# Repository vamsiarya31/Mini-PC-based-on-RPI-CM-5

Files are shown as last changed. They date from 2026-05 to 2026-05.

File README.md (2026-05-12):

# Mini PC — Raspberry Pi Compute Module 5 Carrier Board | KiCad PCB Design

A KiCad-designed **custom carrier board** for the **Raspberry Pi Compute Module 5 (CM5)**, forming a fully functional **Linux-capable Mini PC**. The board interfaces directly with the CM5 module and exposes USB-C, HDMI video output, and microSD Linux boot, powered by a dedicated battery charging and regulation architecture — all designed as a compact multi-sheet hierarchical KiCad project.

You will find the following:
- **Board Schematic:** Hierarchical multi-sheet schematic covering the CM5 interface, HDMI output, USB-C connectivity, microSD boot, battery management, and voltage regulation.
- **PCB Layout:** The physical design of the printed circuit board with component placement and keep-out zones.
- **PCB Routing:** Signal and power routing across the two-layer board following CM5 hardware design guidelines.

---

### Tools Used

The electronic design and development were done using **KiCad**, an open-source EDA software.
The version used for this project is **KiCad 9.0.7**.

#### Footprints used for LEDs:
`0603_1608Metric_Pad1.08x0.95mm_HandSolder`

#### Footprints used for Resistors, Capacitors, Inductors:
`0402_1005Metric_Pad1.22x1.35mm_HandSolder`

All the files are attached in the repository folder.

A custom library was created to import certain symbols into the schematic along with their corresponding footprints and 3D models.

The name of the library is:
- **My library.pretty** : for footprints

---

## System Architecture

The design is organised into **8 hierarchical KiCad sub-sheets**:

| Sub-sheet | File | Function |
|---|---|---|
| RPI-CM5 | `rpicm5.kicad_sch` | CM5108064 module — all peripheral signal routing |
| HDMI | `hdmi.kicad_sch` | HDMI Type-A connector + DDC pull-ups + HPD |
| USB-C | `usbc.kicad_sch` | USB-C receptacle (16-pin, USB 2.0) + CC resistors |
| SD-CARD | `sd.kicad_sch` | MicroSD card slot — 4-bit SDIO boot interface |
| Power Management | `pm.kicad_sch` | MCP73831 Li-Po charger + charging status LED |
| Buck | `buck.kicad_sch` | TPS63001 buck-boost — stable 3.3V from battery input |
| LDO | `ldo.kicad_sch` | LM1117LD-1.8 LDO — fixed 1.8V from regulated input |
| Battery Connector | `bat.kicad_sch` | 2-pin Li-Po battery input connector (J1) |

---

## CM5 Module Interface

The **Raspberry Pi CM5 (CM5108064)** is the central compute element, split across two symbol units (**U1A** and **U1B**) in the schematic to manage its large pin count:

| Interface | CM5 Pins | Carrier Function |
|---|---|---|
| +5V Supply (Input) | 77, 98, 135 | Carrier 5V power rail into CM5 |
| CM5_3.3V (Output) | 84, 86 | CM5-generated 3.3V — internal use |
| CM5_1.8V (Output) | 88, 90 | CM5-generated 1.8V — feeds `1.8v` net on carrier |
| HDMI0 Clock | HDMI0_CLK_P/N (188/190) | Differential clock to HDMI connector |
| HDMI0 TX0–TX2 | TX0_P/N, TX1_P/N, TX2_P/N | TMDS data lanes to HDMI connector |
| HDMI0 Control | HDMI0_SCL (200), HDMI0_SDA (199), HDMI0_HOTPLUG (153) | DDC I2C + HPD to HDMI connector |
| USB 2.0 | USB_P (105), USB_N (103) | D+/D− routed to USB-C receptacle |
| SD Interface | SD_CLK (57), SD_CMD (62), SD_DAT0–3 (63/67/69/61) | 4-bit SDIO to microSD slot |
| CC Pull-downs | CC1 (94), CC2 (96) | 5.1 kΩ to GND — configures USB-C device mode |

> **Note:** The CM5 contains its own onboard PMIC that generates all internal rails. The carrier only needs to supply a clean **+5V** to the module's power input pins. The CM5_1.8V output is re-used on the `1.8v` net for carrier-level peripherals.

---

## Key ICs & Design Decisions

### HDMI Output — HDMI Type-A (J4)
- Driven directly by CM5's **HDMI0** peripheral — no external HDMI bridge or level-shifter required
- **TMDS differential pairs** (TX0, TX1, TX2, CLK) routed from CM5 U1B directly to the J4 HDMI_A connector
- **DDC I2C** (SCL/SDA) lines pulled up to 5V via **R9 and R10 (4.7 kΩ each)** for EDID communication with the connected display
- **HPD (Hot-Plug Detect)** pulled up to 5V via **R15 (5.1 kΩ)** — signals monitor presence back to the CM5
- Local decoupling on the connector's 5V supply: **C5 (10 µF) + C6 (0.1 µF)** bulk + bypass

### USB-C — USB 2.0 (J2, USB_C_Receptacle_USB2.0_16P)
- 16-pin USB-C receptacle wired for **USB 2.0 only** — D+ and D− sourced from CM5 USB_P/USB_N pins
- **CC1 and CC2** each pulled down to GND via **R3 and R4 (5.1 kΩ)** — identifies the port as a **USB device (UFP)** and signals a standard 5V/900 mA draw to the host charger
- No active PD controller — the 5.1 kΩ CC resistors alone are sufficient for charger recognition and device-mode configuration
- **VBUS** from the USB-C receptacle is fed into the Power Management sheet as the charging source for the MCP73831

### MicroSD Boot Slot — J5 (Micro_SD_Card)
- Wired to CM5 SDIO in **4-bit mode**: CLK, CMD, DAT0, DAT1, DAT2, DAT3
- All data and command lines pulled up to **3.3V via 10 kΩ resistors** (R5, R6, R7, R8, R14) for clean defined idle states
- **DAT3/CD** pin doubles as card-detect — pulled up on-board for card presence signalling
- Slot powered by the **3p3v** rail with local decoupling: **C3 (10 µF) + C4 (0.1 µF)**
- Compatible with all standard Linux ARM64 boot images (Raspberry Pi OS, Ubuntu Server, etc.)

### Power Architecture

| Stage | IC / Component | Role |
|---|---|---|
| Battery Input | J1 (Conn_01x02) | 2-pin Li-Po battery connector — `BatP` net |
| Li-Po Charger | MCP73831T-2ACI_OT (U2) | Single-cell Li-Ion/Li-Po charger, input from USB-C VBUS |
| Charge Current | R11 (2 kΩ) on PROG pin | Sets charge current: `I = 1000 / 2kΩ` = **500 mA** |
| Charge Status LED | D1 (RED) + R12 (560 Ω) | STAT pin drives LED — ON during charging, OFF when complete |
| Charger Decoupling | C7 + C8 (4.7 µF each) | Stabilises MCP73831 VDD and VBAT rails |
| 3.3V Regulation | TPS63001 (U3) — Buck-Boost | Stable 3.3V (`3p3v`) across full Li-Po discharge range |
| 3.3V Inductor | L1 (2.2 µH) | TPS63001 switching inductor (L1 and L2 pins) |
| 3.3V Decoupling | C9 (10 µF) + C10 (0.1 µF) + C11 (10 µF) + C12 (10 µF) | TPS63001 input/output stabilisation |
| 1.8V Regulation | LM1117LD-1.8 (U5) — LDO | Fixed 1.8V (`1p8v`) from regulated input |
| 1.8V Decoupling | C13 (10 µF) + C14 (22 µF) | LDO input and output stabilisation |

> **Key Insight:** The **TPS63001 is a buck-boost converter** — it steps the Li-Po output both up and down, guaranteeing a stable 3.3V even as the battery discharges below 3.3V (down to 2.5V). This eliminates the brown-out region common in simple LDO-only designs.

### MCP73831T — Li-Po Battery Charger
- Accepts USB-C **VBUS** as the charging input source (`VDD` pin)
- Charges a single-cell Li-Ion/Li-Po via the `BatP` net (VBAT pin)
- Charge current programmed by **R11 (2 kΩ)** on the PROG pin: `I_CHG = 1000 / R_PROG ≈ 500 mA`
- **STAT pin** (open-drain, active-LOW) drives **D1 (RED LED)** through **R12 (560 Ω)** — lights during active charge, turns off on completion
- End-of-charge termination handled internally — no external components required

### TPS63001 — Buck-Boost Converter (3.3V)
- Converts `VIN` (Li-Po, 2.5 V–5.5 V input range) to a stable **3.3V** on the `3p3v` net
- **L1 (2.2 µH)** switching inductor connected to the L1 and L2 pins
- **R13 (100 Ω)** in the feedback path trims the output voltage
- EN and PS/SYNC pins wired for always-on continuous conduction mode

### LM1117LD-1.8 — 1.8V LDO
- Fixed **1.8V** LDO providing the `1p8v` net used by the CM5 interface
- Input decoupled with **C13 (10 µF)**, output decoupled with **C14 (22 µF)**

---

## Global Power Nets

| Net | Source | Consumers |
|---|---|---|
| `BatP` | J1 battery connector | MCP73831 VBAT, TPS63001 VIN |
| `VBUS` | USB-C J2 | MCP73831 VDD (charge input) |
| `5V` | Carrier 5V | CM5 +5V supply pins (77, 98, 135) |
| `3p3v` | TPS63001 VOUT | SD card VDD, carrier peripherals |
| `1p8v` / `1.8v` | LM1117LD-1.8 VOUT | CM5_1.8V interface net |
| `VDD` | Shared carrier rail | HDMI connector 5V, SD card VDD |
| `GND` | Common ground | All sub-sheets |

---

## Schematic

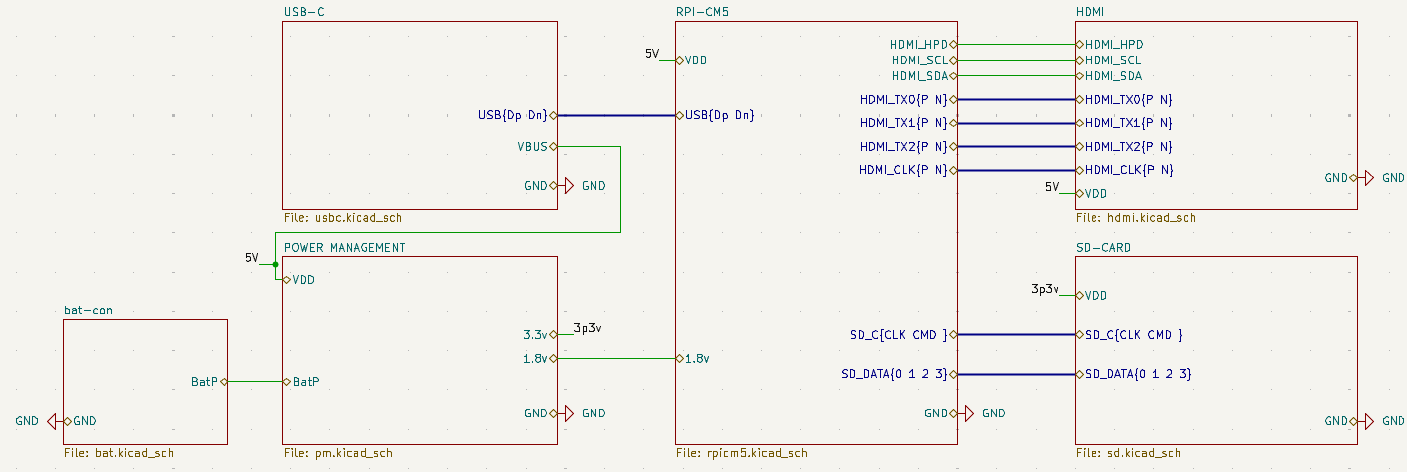
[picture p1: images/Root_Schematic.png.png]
Root Schematic


---

## PCB Layout

### Overall PCB Layout
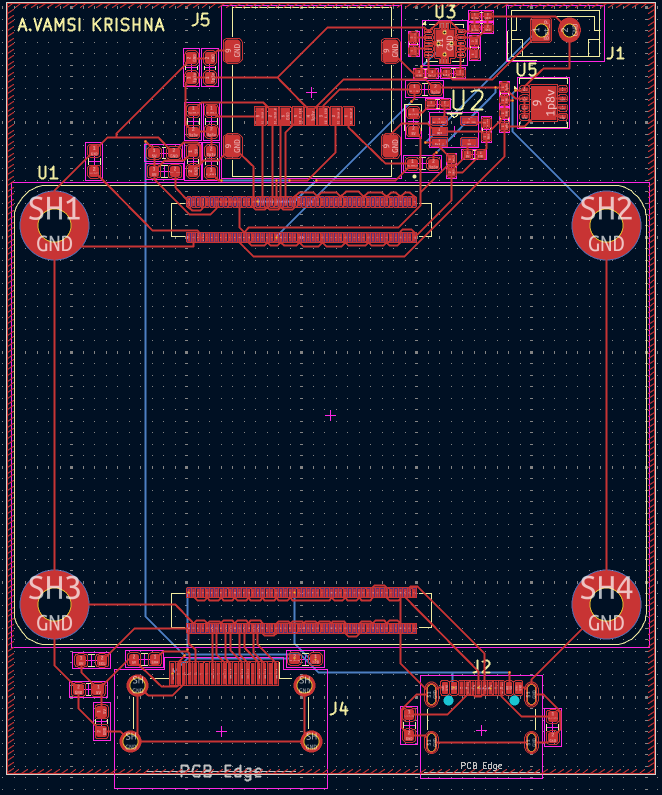
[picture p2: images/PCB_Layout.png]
PCB Layout


---

## 3D View

### Top View 
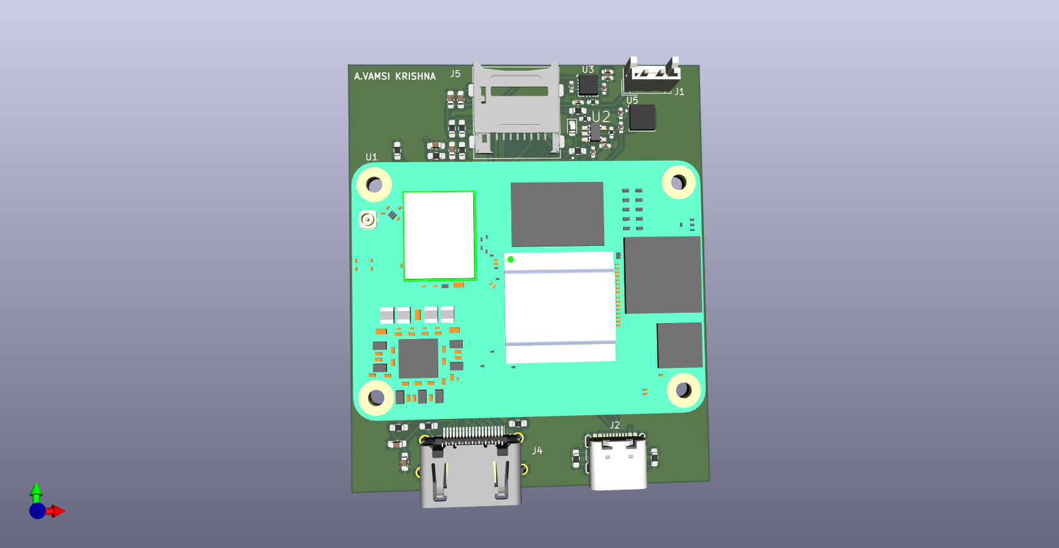
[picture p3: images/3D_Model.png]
3D Top View


### Bottom View 
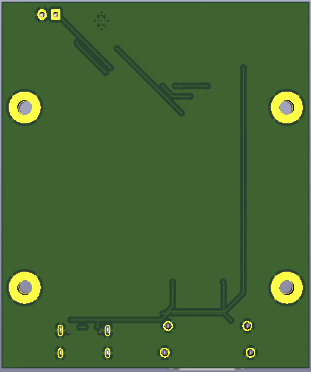
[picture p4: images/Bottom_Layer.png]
3D Bottom View


---

## Board Specifications

| Parameter | Value |
|---|---|
| Layers | 2 |
| Compute Module | Raspberry Pi CM5 (CM5108064) |
| Supply Input | USB-C VBUS (5V) / Li-Po battery |
| Battery Charger | MCP73831T-2ACI_OT — 500 mA charge current |
| 3.3V Regulation | TPS63001 buck-boost (2.5 V – 5.5 V input range) |
| 1.8V Regulation | LM1117LD-1.8 LDO |
| Video Output | HDMI Type-A — CM5 HDMI0 peripheral (TMDS + DDC + HPD) |
| USB | USB-C receptacle — USB 2.0 (D+/D−), device mode via CC pull-downs |
| Boot Storage | MicroSD — 4-bit SDIO (CLK, CMD, DAT0–DAT3) |
| OS Support | Raspberry Pi OS, Ubuntu Server, and any ARM64 Linux distro |

---

## Linux Deployment

The carrier board supports standard Raspberry Pi OS and any ARM64-compatible Linux distribution. To boot:

1. Flash a compatible OS image onto a microSD card using **Raspberry Pi Imager** or `dd`.
2. Insert the microSD into the carrier board's boot slot (J5).
3. Connect a USB-C cable (5V/2A minimum) to J2 for power — this simultaneously charges the Li-Po battery via the MCP73831.
4. Connect a display via the **HDMI Type-A** port (J4).
5. The CM5 will automatically boot from the microSD.

For headless deployment, access the system over **SSH** once the board is on a network.

---

## License



This project is licensed under the MIT License. See the [LICENSE](LICENSE) file for details.

---

## Contact

Vamsi Krishna — Vamsi.Krishna@iiitb.ac.in &nbsp;|&nbsp; [GitHub Profile](https://github.com/vamsiarya31)

Project Link: [https://github.com/vamsiarya31/Mini-PC-based-on-RPI-CM-5](https://github.com/vamsiarya31/Mini-PC-based-on-RPI-CM-5)

---

## Acknowledgments

I would like to express my sincere gratitude to my college, **International Institute of Information Technology (IIIT-B)**, for providing the resources and support to complete this project.  
I am especially grateful to my professor, **Dr. Kurian Polachan**, for their invaluable guidance, encouragement, and expertise throughout the development of this work.

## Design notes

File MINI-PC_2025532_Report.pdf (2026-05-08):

# Design of a Custom Linux-Capable Mini PC using Raspberry Pi Compute Module 5

A. Vamsi Krishna (MT2025532)

Vamsi.Krishna@iiitb.ac.in
IIIT-Bangalore
Project Link (https://github.com/vamsiarya31/Mini-PC-based-on-RPI-CM-5)

Abstract—The growing demand for compact embedded computing systems has accelerated the development of custom Linux-capable platforms for edge computing, IoT, industrial automation, and portable desktop-class applications. This project presents the complete design and implementation of a custom mini PC carrier board based on the Raspberry Pi Compute Module 5 (CM5) using a hierarchical KiCad-based hardware design methodology emphasizing modular subsystem abstraction, practical manufacturability, Linux deployment capability, and scalable embedded computing.
The proposed architecture transforms the CM5 into a standalone Linux-capable mini PC by integrating USB-C power and communication, HDMI display output, microSD-based Linux boot architecture, custom multi-voltage power regulation, and optimized PCB implementation. Unlike conventional off-theshelf Raspberry Pi systems, this work focuses on engineering a dedicated custom carrier board that preserves CM5 computational capabilities while enabling hardware-level customization, subsystem scalability, and deployment-specific design flexibility. Significant emphasis is placed on practical engineering implementation including compute subsystem integration, USB and HDMI interface realization, Linux operating system boot enablement, power-domain partitioning, signal routing optimization, and compact PCB realization. The final implementation demonstrates how a custom CM5 carrier board can serve as a deployable Linux computing platform suitable for embedded systems, educational development, edge computing, and future AI-integrated applications.
Index Terms—Raspberry Pi CM5, Mini PC, Linux Embedded System, KiCad, Custom Carrier Board, HDMI, USB-C, PCB Design, Embedded Computing
I. INTRODUCTION

The rapid evolution of embedded systems has significantly increased the demand for compact, power-efficient, and Linux-capable computing platforms that can bridge the gap between traditional desktop systems and dedicated embedded hardware. Modern applications including IoT gateways, edge computing nodes, robotics controllers, educational platforms, and industrial automation systems increasingly require flexible hardware architectures that combine computational capability with custom hardware integration.
Traditional single-board computers (SBCs) such as standard Raspberry Pi platforms provide accessible Linux computing environments but often impose limitations in subsystem customization, deployment-specific hardware optimization, and PCB-level engineering flexibility. For specialized applications, a custom carrier board architecture provides superior design control by enabling subsystem-specific integration while preserving computational performance.
The Raspberry Pi Compute Module 5 (CM5) provides an ideal foundation for such a platform by integrating processing, RAM, wireless communication, and Linux support into a compact embedded module. However, practical deployment requires a dedicated hardware ecosystem capable of supporting storage, display, communication, and power management. This project presents the complete design and implementation of a custom Linux-capable mini PC using Raspberry Pi CM5. The system integrates:
- Raspberry Pi CM5 compute core
- USB-C power and communication
- HDMI display subsystem
- microSD Linux boot architecture
- Custom 5V/3.3V/1.8V power regulation
- Hierarchical KiCad schematic methodology
- Manufacturable PCB implementation
- Compact mini PC deployment capability

Unlike conventional SBC deployment, this work emphasizes engineering a complete custom embedded motherboard capable of transforming the CM5 into a scalable Linux mini PC platform through practical hardware realization.

A. Engineering Contributions

The primary novelty of this work lies not in merely using Raspberry Pi CM5, but in engineering a custom deployable Linux computing platform through dedicated carrier board realization. Major engineering contributions include:

- Custom CM5 carrier board instead of standard SBC deployment
- Hierarchical KiCad-based hardware abstraction
- Linux-capable embedded ecosystem realization
- Multi-voltage power subsystem engineering
- HDMI, USB-C, and storage interface integration
- Manufacturable PCB design with practical deployment focus
This | transforms | the | project | from | a | conventional
development-board implementation into a custom embedded computing platform with deployment-specific scalability.

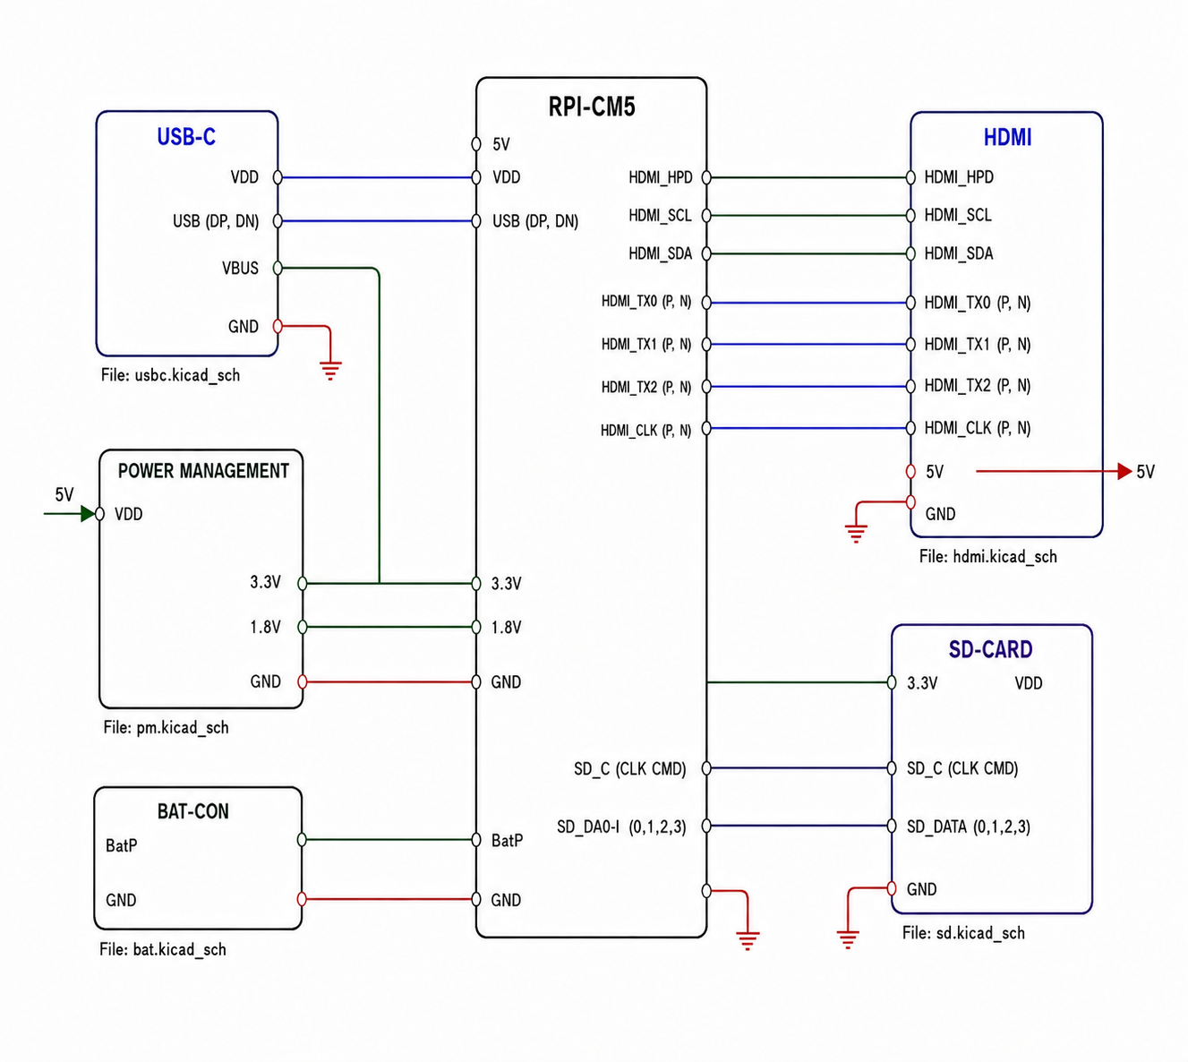
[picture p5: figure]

Fig. 1: Hierarchical Root Schematic

II. SYSTEM DESIGN

A. Overall System Architecture
The proposed mini PC architecture consists of four major subsystems:
1) Raspberry Pi CM5 Compute Core
2) USB-C Power and Communication Interface
3) HDMI Display Output Subsystem
4) microSD Linux Boot and Storage Architecture
The complete design was implemented using hierarchical KiCad schematic abstraction to improve modularity, maintainability, subsystem debugging, and scalable PCB realization. Rather than implementing the system as a monolithic design, hierarchical partitioning enables structured hardware abstraction where each subsystem can be independently developed, validated, and integrated.
This methodology significantly improves engineering workflow while also enabling future subsystem upgrades such as additional I/O expansion, thermal optimization, or AI hardware integration.
B. System Block Diagram
The functional system workflow of the proposed architecture can be summarized as:

USB-C → P ower Regulation → CM5 → HDMI/USB (1)
This block-level abstraction highlights the power-tocompute-to-interface design philosophy used throughout implementation.
C. Raspberry Pi Compute Module 5 Integration
The Raspberry Pi CM5 serves as the central computational subsystem of the proposed mini PC platform. It integrates processor, memory, wireless communication, and Linux support within a compact modular architecture.

Key features include:
- Linux operating system compatibility
- Integrated RAM architecture
- Wi-Fi and BLE connectivity
- Compact embedded design
- GPIO and peripheral expansion capability
- Scalable deployment flexibility
By leveraging the CM5 rather than a traditional SBC board, the proposed design enables full computational capability while allowing custom hardware-level engineering. This significantly improves platform adaptability for deployment-specific applications.
D. USB-C and HDMI Interface
USB-C serves as the primary power input and communication subsystem, providing a modern standardized interface for reliable system deployment. HDMI provides external monitor compatibility, enabling desktop-class Linux system visualization.
The HDMI subsystem supports:
- Differential display signaling
- Clock and data routing
- Hot-plug detection
- Display communication
- External monitor compatibility
Together, these interfaces transform the hardware platform from a compute module carrier into a practical standalone Linux mini PC.
Unlike conventional Raspberry Pi SBC deployment, the proposed design provides deployment-specific hardware customization, modular scalability, and custom manufacturable embedded system realization.
E. Linux Boot Architecture and OS Deployment
A major engineering objective of the project is enabling complete Linux operating system deployment on the Raspberry Pi CM5 through external storage architecture. Unlike conventional desktop systems, Raspberry Pi platforms do not operate with a preloaded Linux environment by default. Instead, the operating system must first be installed onto a bootable storage medium such as a microSD card or SSD. Linux deployment is performed using Raspberry Pi Imager, which flashes Raspberry Pi OS or Ubuntu Linux onto the storage device by writing the required boot files, firmware, kernel image, and root filesystem. This process effectively “dumps” the operating system image onto storage in a bootable format compatible with Raspberry Pi hardware.
The Linux installation workflow can be summarized as:

Raspberry P i Imager → microSD/SSD → Bootable Linux (2)
Once powered on, the CM5 bootloader reads the boot files from the storage medium, initializes firmware, configures memory and peripheral interfaces, loads the Linux kernel into RAM, and launches the operating system.

The Linux boot workflow consists of sequential initialization stages:

Bootloader → Firmware
→ Linux Kernel
→ Device Tree
→ Root Filesystem | (3)

In simple terms:
- Raspberry Pi Imager: Writes Linux onto storage
- Bootloader: Reads and initializes boot files
- Kernel: Loads and controls hardware resources
- Root Filesystem: Launches the complete Linux environment
This subsystem is particularly important because it transforms the proposed hardware platform from a custom PCB implementation into a fully operational Linux-capable mini PC suitable for desktop operation, embedded deployment, and software scalability.
F. Power Management
Reliable power architecture is essential for stable Linux-capable embedded operation. Since the platform integrates compute, storage, display, and communication subsystems, stable multi-voltage regulation is critical for boot reliability and peripheral compatibility.
The design integrates:
- USB-C 5V primary input
- 3.3V regulated subsystem for SD and interface logic
- 1.8V support rail for low-voltage peripheral requirements
- Multi-domain power distribution
- Stable peripheral supply hierarchy
A structured regulator hierarchy ensures voltage compatibility across subsystem domains while minimizing instability during Linux boot initialization. Proper voltage sequencing is particularly important because storage, firmware loading, and interface initialization depend on stable supply conditions. This power architecture significantly improves deployment reliability by ensuring that compute, storage, and communication domains operate under consistent electrical conditions.
G. PCB Design Considerations
PCB implementation was carefully optimized to balance compact form factor, manufacturability, and subsystem routing integrity.
Key considerations include:
- Compact component placement for mini PC realization
- Logical subsystem partitioning
- USB-C and HDMI routing practicality
- Mounting-hole mechanical stability
- Bottom-layer routing optimization
- Future hardware scalability
These considerations ensure the design is not merely functional but also practical for deployment, assembly, and future expansion.


Fig. 2: PCB Layout

III. RESULTS

The complete custom Linux-capable mini PC platform was successfully implemented using KiCad schematic development, PCB layout design, and 3D hardware visualization. The final implementation demonstrates practical subsystem integration, hardware manufacturability, Linux deployment readiness, and compact embedded platform realization.
The PCB layout demonstrates optimized subsystem partitioning, compact component placement, practical routing, and deployment-focused hardware organization.
Functional outcomes include:
- Hierarchical schematic architecture realization
- Functional Raspberry Pi CM5 carrier board deployment
- Linux boot-capable embedded system platform
- HDMI display subsystem integration
- USB-C and microSD deployment
- Manufacturable compact PCB realization
A. Applications

The proposed platform can support multiple practical deployment domains including:
- Edge computing node
- IoT gateway
- Robotics controller
- Educational Linux workstation
- Embedded development platform
This broadens the relevance of the project beyond prototype hardware into practical embedded deployment.

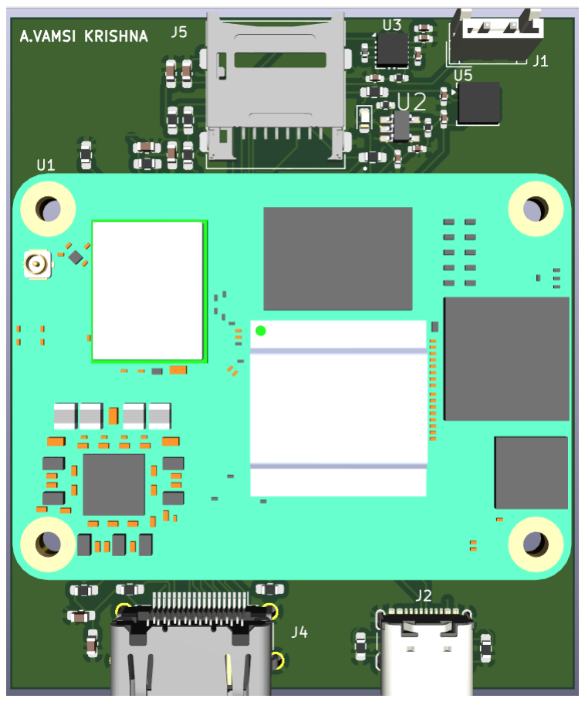
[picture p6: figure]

Fig. 3: Top View of the 3D Model


Fig. 4: Bottom View of the 3D Model

IV. CONCLUSION

This work presented the complete design and implementation of a custom Linux-capable mini PC using Raspberry Pi Compute Module 5 through hierarchical KiCad-based hardware development methodology.
The proposed platform successfully integrates compute, power, storage, display, and Linux boot architecture into a unified custom carrier board. Unlike conventional Raspberry Pi deployment approaches, this project emphasizes engineeringfocused motherboard realization that prioritizes subsystem customization, PCB manufacturability, Linux deployment capability, and scalable embedded design.
The project demonstrates that Raspberry Pi CM5 can be effectively transformed into a dedicated Linux-capable mini PC platform through practical hardware engineering while maintaining flexibility for future deployment in embedded systems, edge computing, educational development, and advanced AI-integrated architectures.
V. FUTURE SCOPE
Future improvements can focus on enhancing performance, scalability, and deployment versatility of the proposed Linux-capable mini PC platform.
- Thermal Management: Integration of heatsinks, cooling fans, or thermal-aware PCB design can improve sustained performance and reduce thermal throttling under extended workloads.
- AI and Edge Acceleration: External TPU/NPU or PCIe/USB-based AI modules can enable machine learning, computer vision, and edge-computing applications.
- Multi-USB and GPIO Expansion: Additional USB hubs and GPIO interfaces can improve peripheral connectivity for IoT, robotics, and embedded system development.

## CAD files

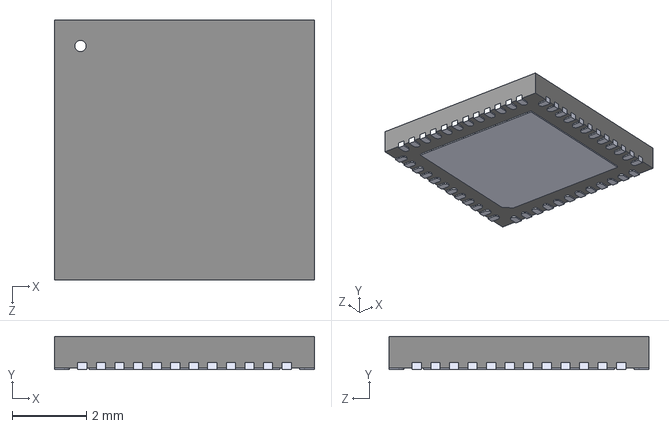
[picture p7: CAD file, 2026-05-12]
3D models Imported/KSZ9031RNXCC-TR.step
7.00 x 0.9 x 7.00 mm

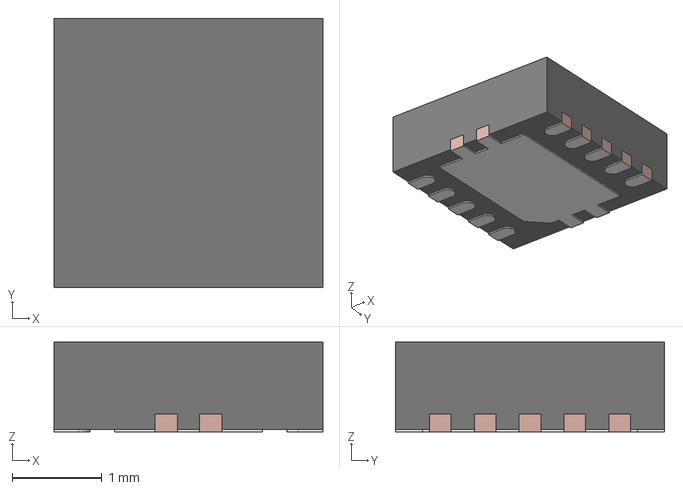
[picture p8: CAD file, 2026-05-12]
3D models Imported/DRC0010J.stp
3.00 x 3.00 x 1.00 mm
BODY-SON
FRAME-DRC0010J

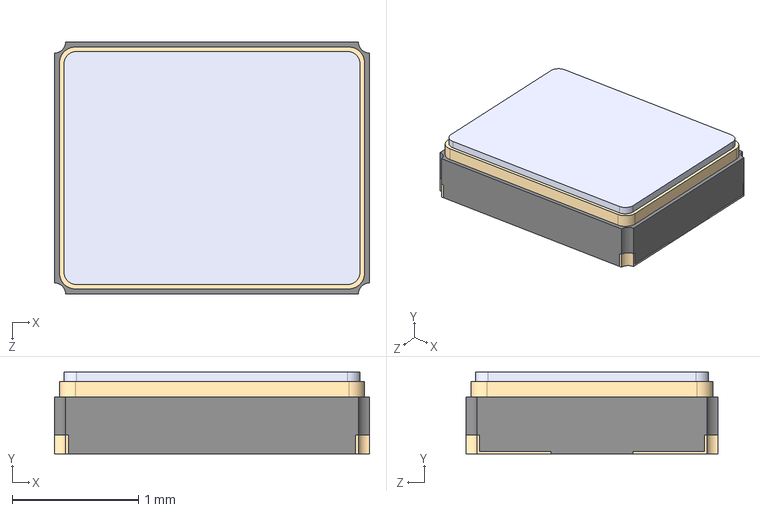
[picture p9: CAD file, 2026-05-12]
3D models Imported/ECS-250-8-36CKM-TR.step
2.50 x 0.65 x 2.00 mm

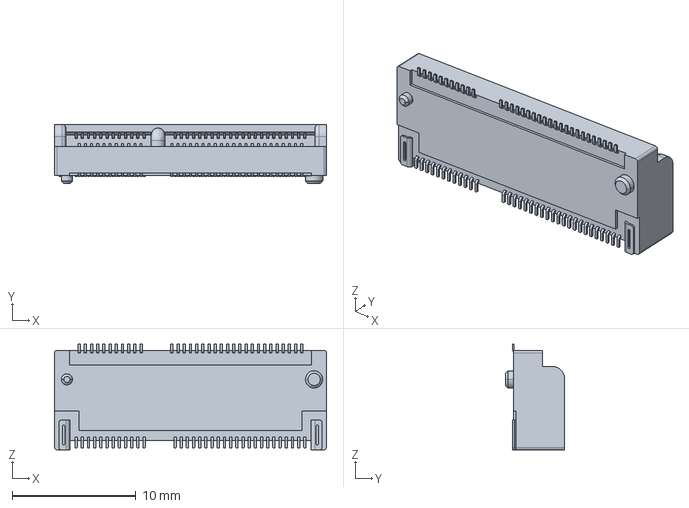
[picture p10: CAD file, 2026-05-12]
3D models Imported/MDT420E01001.step
22.0 x 4.80 x 8.55 mm

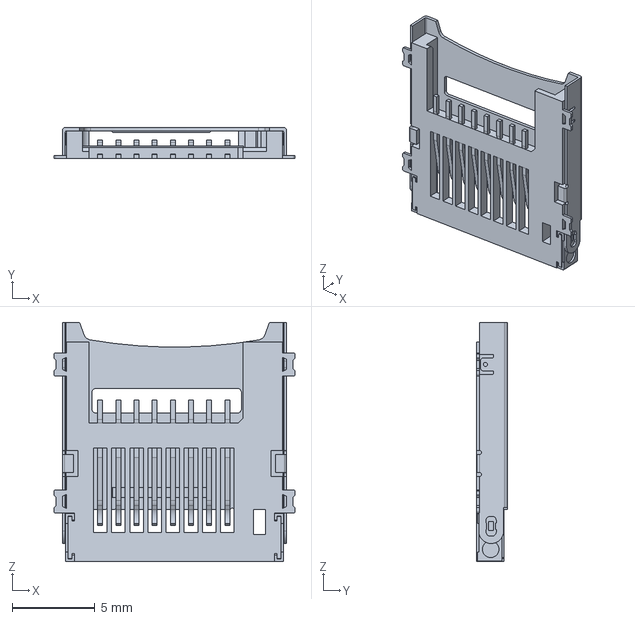
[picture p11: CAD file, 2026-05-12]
3D models Imported/472192001.stp
14.6 x 1.90 x 14.5 mm

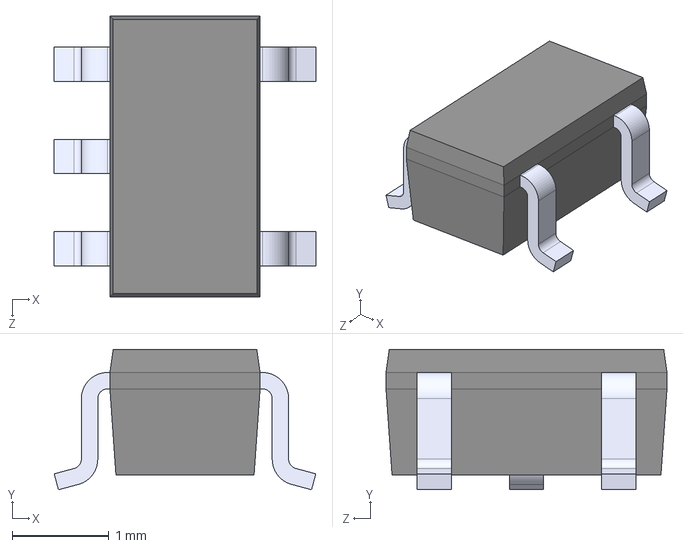
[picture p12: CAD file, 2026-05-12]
3D models Imported/MCP73831T-2ACI_OT.step
2.70 x 1.45 x 2.90 mm
